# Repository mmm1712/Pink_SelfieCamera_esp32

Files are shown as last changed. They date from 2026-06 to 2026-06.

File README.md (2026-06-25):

# PocketCam: Pink ESP32S3 DIY Camera

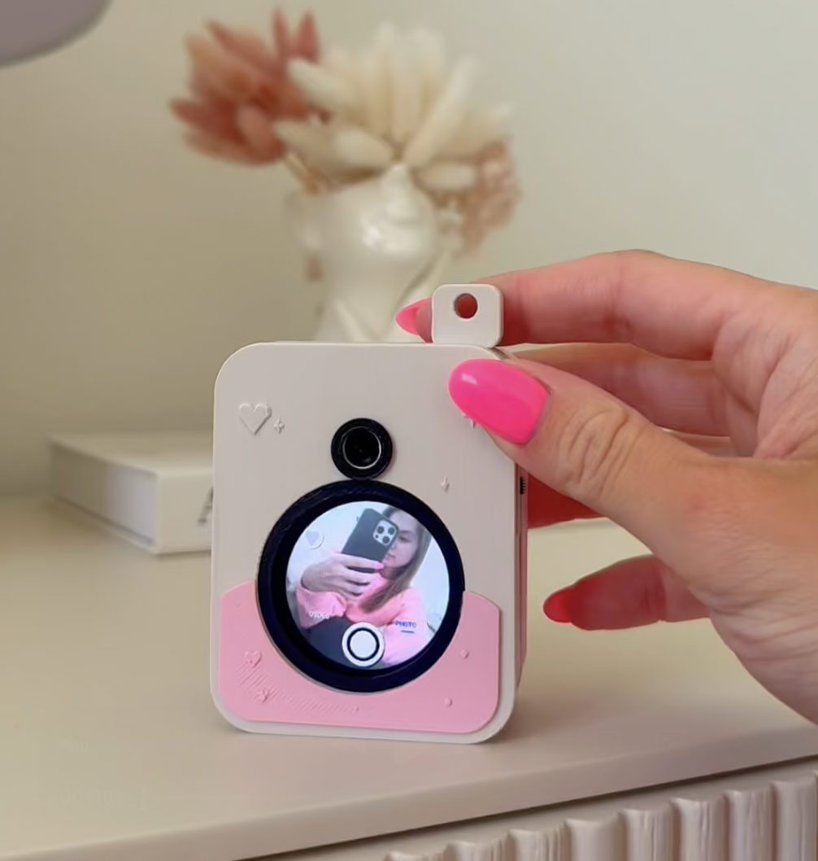
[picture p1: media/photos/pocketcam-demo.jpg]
PocketCam demo


## Demo Video

PocketCam demo video (https://youtu.be/CbtFV22GO2s)

Watch the full build/demo video on YouTube: https://youtu.be/CbtFV22GO2s

A tiny pink DIY camera built with a Seeed XIAO ESP32S3 Sense, an OV3660 camera module, a round display, microSD storage, a LiPo battery, and a custom 3D printed enclosure.

The goal of this project was to make a small camera that feels more like a real mini product than a loose electronics prototype. PocketCam shows a live preview on the round screen, captures photos and videos, saves them to microSD, creates its own local Wi-Fi network, and lets an iPhone connect directly to sync photos into a custom SwiftUI app.

This repository includes the ESP32 firmware, iPhone app, 3D printed enclosure files, hardware notes, and documentation for the project.

## What Makes It Interesting

* The ESP32S3 acts as a standalone camera and local Wi-Fi access point.
* The camera exposes a small HTTP API for syncing photos and videos.
* The iPhone app talks directly to the camera without internet or cloud.
* Photos and videos are saved locally to the microSD card.
* The iPhone app adds a gallery, filters, and on-device Core ML enhancement.
* The enclosure was designed from scratch to make the project feel like a real small device.

## Features

* Live camera preview on a round display
* Photo and video capture
* microSD card saving
* Local Wi-Fi access point mode
* Local web server for syncing
* iPhone SwiftUI app for gallery and photo sync
* Photo filters
* On-device Enhance feature using a compact Real-ESRGAN Core ML model
* Custom OpenSCAD 3D printed enclosure
* Battery-powered design with a physical power switch
* Small product-style case instead of a breadboard prototype

## Hardware

Main parts used:

| Part | Description |
| --- | --- |
| Seeed XIAO ESP32S3 Sense | Main microcontroller board |
| OV3660 camera module | Camera sensor |
| Seeed round display for XIAO | 1.28 inch round display |
| microSD card | Local photo/video storage |
| LiPo battery | Portable power |
| Slide switch | Main power switch |
| Custom 3D printed enclosure  | Front shell, back cover, openings, and internal fit |
| Screws / brass inserts | Used for assembly |
| Small wires / heat tape | Internal wiring and insulation |

## Software / Firmware

The ESP32 firmware handles the main camera behavior:

* Camera initialization
* Round display live preview
* Photo and video capture
* Saving files to microSD
* Creating a local Wi-Fi access point
* Running a small local web server
* Sending saved files to the iPhone app

The camera creates its own Wi-Fi network, so it does not need internet or a router. The iPhone connects directly to the camera and downloads files over the local network.

## Camera API

The ESP32 hosts a small local HTTP server used by the iPhone app.

Example endpoints:

```txt
GET /status.json
GET /photos.json?since=0&limit=12
GET /photo?id=123
GET /latest
GET /videos.json?since=0&limit=1
GET /video?id=5
GET /capture
```

These endpoints are used to check the camera status, list saved media, download photos/videos, and trigger capture from the app.

## iPhone App

The iPhone app was built with SwiftUI.

It can:

* Connect to the PocketCam Wi-Fi network
* Check for saved photos
* Sync photos from the camera
* Show photos in a gallery
* Apply additional filters
* Run an on-device Enhance feature using a compact Real-ESRGAN Core ML model

The app is not meant to be a full production camera app. It is a companion app for the hardware prototype and helps make the project feel more complete.

## 3D Printed Enclosure

The enclosure was designed in OpenSCAD and 3D printed.

The case includes:

* Round display opening
* Camera/lens opening
* Back cover
* Screw bosses
* Battery space
* Power switch opening
* Internal space for the XIAO ESP32S3 Sense and wiring

A big part of this project was making the camera look and feel like a real small device, not just a working prototype. I spent a lot of time adjusting the case design, screw bosses, display opening, lens opening, back cover, and internal fit so the electronics could fit inside a small enclosure.

## Folder Structure

```txt
Pink_SelfieCamera_esp32/
├── README.md
├── firmware/
│   └── README.md
├── ios-app/
│   └── README.md
├── enclosure/
│   ├── README.md
│   ├── openscad/
│   └── stl/
├── hardware/
│   └── BOM.md
├── docs/
│   ├── images/
│   ├── wiring.md
│   ├── assembly.md
│   └── sync-flow.md
└── media/
    ├── photos/
    └── videos/
```

## How It Works

PocketCam has three main parts:

1. **ESP32S3 camera firmware**
   The ESP32S3 reads from the camera module, shows a live preview on the round display, and saves captured photos/videos to the microSD card.

2. **Local Wi-Fi sync**
   The camera creates its own Wi-Fi access point. The iPhone connects directly to that network and communicates with the ESP32 through local HTTP endpoints.

3. **iPhone gallery app**
   The SwiftUI app checks the camera for saved files, downloads them, and shows them in a simple gallery. The app also includes filters and on-device photo enhancement.

Basic flow:

```txt
Camera module
   ↓
ESP32S3 firmware
   ↓
Round display live preview
   ↓
Save photo/video to microSD
   ↓
Create local Wi-Fi network
   ↓
iPhone connects directly
   ↓
SwiftUI app syncs photos into gallery
   ↓
Filters + on-device Enhance
```

## Limitations

This is still a DIY prototype, so there are some limitations:

* Image quality is limited by the small camera module.
* Preview frame rate is not as smooth as a phone camera.
* Wi-Fi sync is local only.
* Battery life depends on battery size, display usage, and Wi-Fi activity.
* The enclosure may need small tolerance adjustments depending on the 3D printer.
* Internal wiring is compact and needs careful assembly.
* The iPhone app is currently a companion app, not a full App Store-ready product.

## Future Improvements

Possible next steps:

* Design a custom PCB to reduce wiring
* Improve battery charging and power management
* Make the enclosure easier to assemble
* Improve video recording stability
* Add more camera modes
* Improve sync speed
* Polish the iPhone app UI
* Add a full beginner-friendly assembly guide
* Add better face-centered crop or portrait-style effects
* Improve internal mounting for the display, battery, and switch

## Credits

AI photo enhancement is based on [Real-ESRGAN](https://github.com/xinntao/Real-ESRGAN).

The model is used as a compact Core ML model for on-device inference inside the iPhone app. I integrated it into the app; I did not train Real-ESRGAN from scratch.

Hardware is based around the Seeed XIAO ESP32S3 Sense and the Seeed round display for XIAO.

## Project Status

Working prototype. Still improving the enclosure, wiring, app UI, and overall polish.

## License

Code is licensed under the MIT License. See [LICENSE](LICENSE).

OpenSCAD and STL enclosure files are licensed under Creative Commons Attribution 4.0 International — CC BY 4.0. See [LICENSE-CAD.md](LICENSE-CAD.md).

Real-ESRGAN and any related model files follow their own upstream license and credits.

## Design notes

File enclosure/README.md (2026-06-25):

# 3D Printed Enclosure

This folder contains the 3D printed enclosure files for the Pink Selfie Camera ESP32 project.

The enclosure was designed to make the camera feel more like a real small product instead of a loose electronics prototype.

## Design Goals

The case was designed around:

* Seeed XIAO ESP32S3 Sense
* OV3660 camera module
* Seeed round display for XIAO
* LiPo battery
* Slide power switch
* Internal wiring
* Screw bosses and back cover

The main goal was to fit all electronics inside a small pink camera-style enclosure while keeping the round display and camera opening visible from the front.

## Folder Structure

```txt
enclosure/
├── README.md
├── openscad/
│   └── .scad files
└── stl/
    └── .stl files
```

## OpenSCAD Files

The `openscad/` folder contains the editable CAD source files.

Use these files if you want to modify the case design, adjust tolerances, change screw boss length, or update the internal layout.

## STL Files

The `stl/` folder contains exported 3D printable files.

Use these files if you just want to print the enclosure without editing the OpenSCAD design.

## Enclosure Features

* Round display opening
* Camera/lens opening
* Back cover
* Screw bosses
* Battery space
* Power switch opening
* Internal room for the XIAO ESP32S3 Sense
* Space for wires and insulation
* Small product-style shape

## Print Notes

This is a compact enclosure, so small tolerance differences can matter.

Recommended checks after printing:

* Make sure the round display fits
* Make sure the camera opening is clear
* Check that the back cover closes
* Check that screw bosses are not too tight
* Make sure the switch opening is usable
* Confirm the battery is not squeezed

## Prototype Notes

The enclosure went through multiple design changes to improve fit, back cover alignment, screw bosses, display opening, lens opening, and internal hardware placement.

This version is still a prototype, so small adjustments may be needed depending on printer calibration, filament, screws, and final hardware placement.

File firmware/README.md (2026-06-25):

# ESP32 Firmware

This folder contains the firmware for the Pink Selfie Camera ESP32 project.

The firmware runs on the Seeed XIAO ESP32S3 Sense and controls the camera, round display, microSD storage, local Wi-Fi access point, and sync endpoints.

## Main Responsibilities

The firmware handles:

* Initializing the OV3660 camera module
* Showing a live preview on the round display
* Capturing photos and videos
* Saving media files to the microSD card
* Creating a local Wi-Fi access point
* Running a small local web server
* Providing endpoints for the iPhone app to sync media

## Hardware Target

Main board:

```txt
Seeed XIAO ESP32S3 Sense
```

Main connected parts:

```txt
OV3660 camera module
Seeed round display for XIAO
microSD card
LiPo battery
Power switch
```

## Local Wi-Fi Mode

The camera runs in access point mode.

This means the ESP32 creates its own Wi-Fi network, and the iPhone connects directly to it.

Example public/demo settings:

```cpp
const char* ssid = "PocketCam-0001";
const char* password = "change_this_password";
```

Do not upload private Wi-Fi passwords or personal credentials to GitHub.

## Camera API

The firmware exposes a small local HTTP API.

Example endpoints:

```txt
GET /status.json
GET /photos.json?since=0&limit=12
GET /photo?id=123
GET /latest
GET /videos.json?since=0&limit=1
GET /video?id=5
GET /capture
```

The iPhone app uses these endpoints to check status, list media, download photos/videos, and trigger capture.

## Notes

This firmware is built for a working prototype. The current focus is making the hardware, display, storage, Wi-Fi sync, and iPhone app work together in one small camera.

Future firmware improvements could include:

* Cleaner state machine
* Better video recording stability
* Faster sync
* More reliable reconnect behavior
* Better battery/power handling
* More camera settings
* Improved UI feedback on the round display

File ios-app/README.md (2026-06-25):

# iPhone App

This folder contains the iPhone companion app for the Pink Selfie Camera ESP32 project.

The app was built with SwiftUI and is used to connect to the camera, sync photos, show them in a gallery, apply filters, and run an on-device Enhance feature.

## What the App Does

The app can:

* Connect to the PocketCam Wi-Fi network
* Check the ESP32 camera status
* List saved photos and videos
* Sync new photos from the camera
* Display synced photos in a gallery
* Apply photo filters
* Run an on-device Enhance feature using a compact Real-ESRGAN Core ML model

## How It Connects

The camera creates its own local Wi-Fi network.

The iPhone connects directly to that network, then the app communicates with the ESP32 through local HTTP endpoints.

Example camera address:

```txt
http://192.168.10.1
```

Example endpoints used by the app:

```txt
/status.json
/photos.json
/photo?id=123
/latest
/videos.json
/video?id=5
/capture
```

## On-Device Enhance

The app includes an Enhance feature using a compact Real-ESRGAN Core ML model.

This runs locally on the iPhone. It does not require internet or cloud processing.

I integrated the Core ML model into the app, but I did not train Real-ESRGAN from scratch.

## Current Prototype Notes

This app is a companion app for the hardware prototype, not a full production App Store camera app.

Future app improvements could include:

* More polished UI
* Better sync progress indicators
* Faster thumbnail loading
* More reliable reconnect behavior
* Better photo/video organization
* Settings screen for camera options
* Cleaner delete/select flow

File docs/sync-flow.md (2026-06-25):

# Sync Flow

PocketCam syncs photos from the ESP32 camera to the iPhone app over a local Wi-Fi connection.

The camera does not need internet, a router, or cloud storage. The ESP32 creates its own Wi-Fi network, and the iPhone connects directly to it.

## Basic Flow

```txt
PocketCam powers on
      ↓
ESP32S3 starts camera + round display
      ↓
Photos/videos are saved to microSD
      ↓
ESP32S3 creates a local Wi-Fi access point
      ↓
iPhone connects to the PocketCam Wi-Fi network
      ↓
SwiftUI app talks to the ESP32 local web server
      ↓
App downloads photos/videos into the phone gallery
```

## Local Wi-Fi

The ESP32S3 runs in access point mode.

That means the camera creates its own Wi-Fi network instead of connecting to a home router.

Example:

```txt
Wi-Fi name: PocketCam-0001
Password: change_this_password
IP address: 192.168.10.1
```

## Local Web Server

The ESP32 hosts a small local HTTP server.

The iPhone app uses simple endpoints to check camera status, list saved files, and download media.

Example endpoints:

```txt
GET /status.json
GET /photos.json?since=0&limit=12
GET /photo?id=123
GET /latest
GET /videos.json?since=0&limit=1
GET /video?id=5
GET /capture
```

## Photo Sync

Photos are saved to the microSD card first.

Then the iPhone app asks the camera which files are available, downloads the new ones, and shows them in a gallery.

```txt
Photo captured
      ↓
Saved to microSD
      ↓
Listed by ESP32 web server
      ↓
Downloaded by iPhone app
      ↓
Displayed in SwiftUI gallery
```

## Why This Design

I chose local Wi-Fi sync because it keeps the project simple and portable.

Benefits:

* No internet required
* No cloud account required
* Photos stay local unless synced
* The camera can work anywhere
* The iPhone app can communicate directly with the hardware

## Current Prototype Notes

This sync system is designed for a small DIY prototype. It works well for local photo transfer, but it is not meant to be a high-speed production camera system.

Future improvements could include faster sync, better file indexing, progress indicators, and more reliable reconnect behavior.

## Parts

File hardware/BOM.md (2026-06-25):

# Bill of Materials

Main hardware used for the Pink Selfie Camera ESP32 project.

| Part | Purpose | Notes |
| --- | --- | --- |
| Seeed XIAO ESP32S3 Sense | Main microcontroller | Runs the camera firmware, Wi-Fi server, and microSD logic |
| OV3660 camera module | Camera sensor | Used for live preview and photo/video capture |
| Seeed Round Display for XIAO | Camera screen | Shows the live round preview |
| microSD card | Local storage | Stores captured photos and videos |
| LiPo battery | Portable power | Powers the camera without USB |
| Slide power switch | Power control | Used to turn the camera on/off |
| 3D printed front shell | Enclosure | Custom designed in OpenSCAD |
| 3D printed back cover | Enclosure | Covers electronics and battery |
| Screws / brass inserts | Assembly | Used to close the enclosure |
| Small wires | Internal wiring | Used for battery and switch connections |
| Heat tape / insulation tape  | Safety | Covers solder joints and prevents shorts |

## Notes

This project is built as a compact prototype, so the internal space is limited. The battery, switch, display, camera module, and wiring all need to fit inside the 3D printed enclosure.

The exact battery size and screw lengths may need small adjustments depending on the final case version and 3D print tolerances.

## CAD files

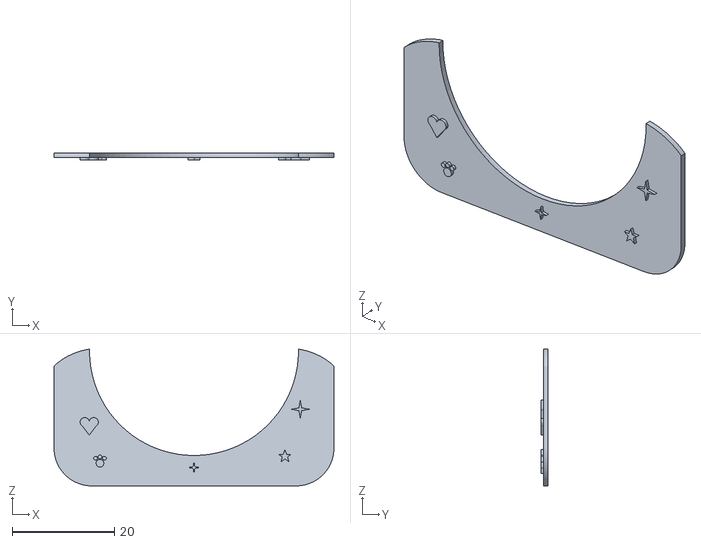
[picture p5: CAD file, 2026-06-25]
enclosure/stl/accent_panel.stl
54.8 x 1.46 x 26.8

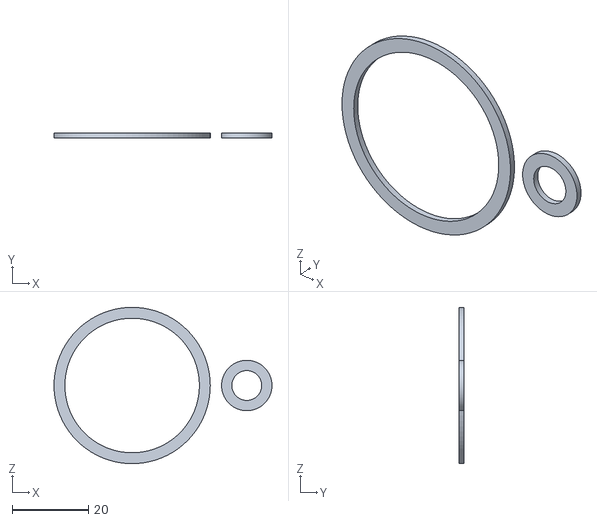
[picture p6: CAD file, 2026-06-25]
enclosure/stl/bezel_rings.stl
57.0 x 1.25 x 40.9

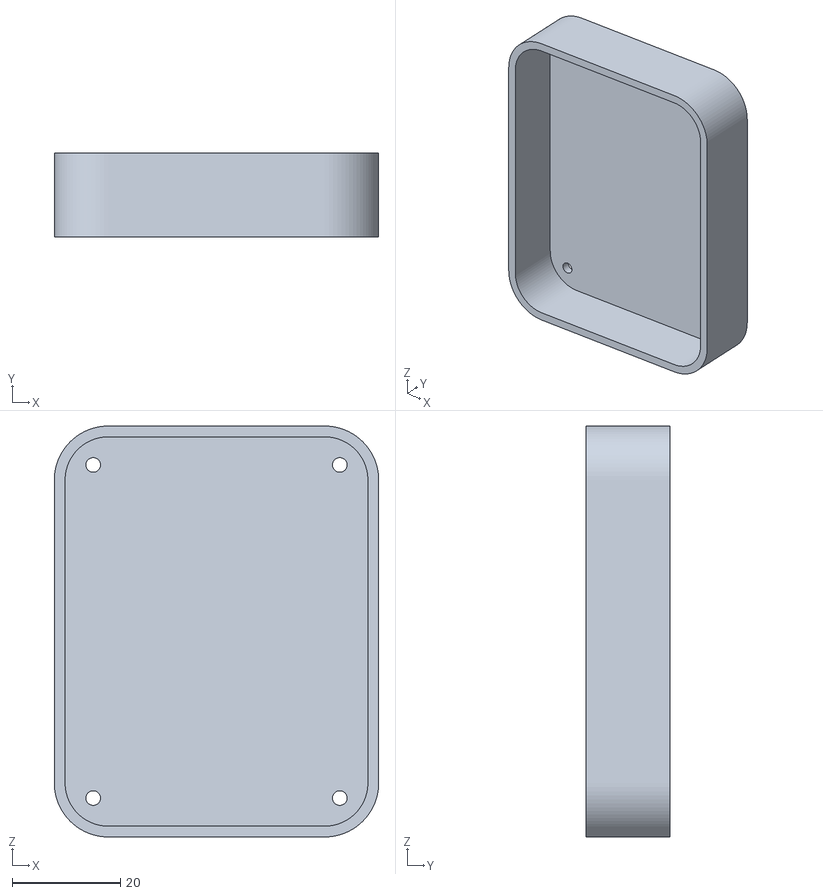
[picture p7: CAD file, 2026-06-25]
enclosure/stl/back_cover.stl
60.0 x 15.5 x 76.0

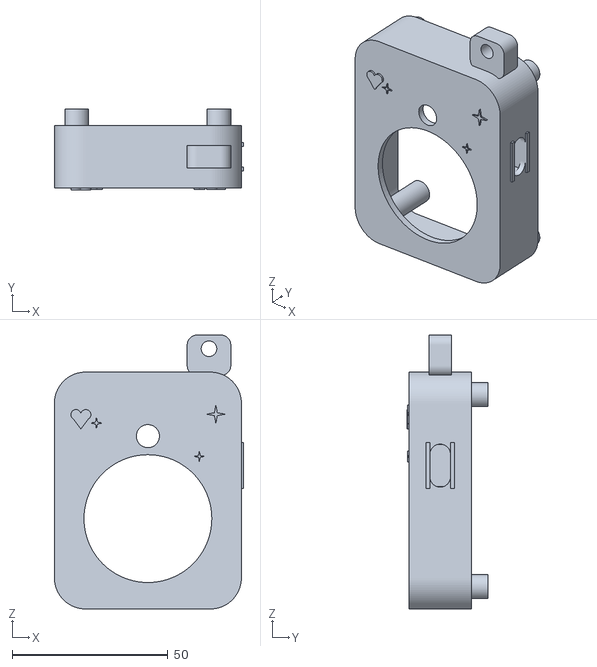
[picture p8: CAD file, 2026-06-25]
enclosure/stl/front_shell.stl
60.7 x 26.0 x 87.9

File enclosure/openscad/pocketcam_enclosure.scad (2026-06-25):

$fn = 80;


// part = "assembly";
// part = "back_cover";
// part = "accent_panel";
// part = "bezel_rings";
// part = "front_fit_test";
// part = "battery_fit_test";
// part = "display_screw_template";
// part = "front_shell";

part = "front_shell";


body_w = 60;

body_h_base = 66;
top_extra = 10;
body_h = body_h_base + top_extra;

body_z_shift = top_extra / 2;
body_bottom_z = -body_h_base / 2;
body_top_z = body_bottom_z + body_h;

front_depth = 20.0;


back_depth = 20.5;


lid_lip_depth = 5.0;
lid_lip_wall = 1.2;
lid_lip_clearance = 0.65;
lip_overlap = 2.0;   


back_outer_depth = back_depth - lid_lip_depth;

body_depth = front_depth + back_outer_depth;

corner_r = 10.0;
wall = 2.0;
front_face_t = 2.3;
clearance = 0.45;

xiao_w = 21.0;
xiao_h = 17.8;
xiao_t = 3.2;
xiao_sense_stack_t = 15.0;

round_display_pcb_d = 39.0;
round_display_visible_d = 34.5;
round_display_recess_d = 41.0;

battery_w = 33.0;
battery_h = 43.0;
battery_t = 10.5;

lens_hole_d = 7.4;
lens_bezel_outer_d = 12.2;
lens_bezel_inner_d = 7.8;

screen_z = -4.0;
lens_z = screen_z + round_display_visible_d/2 + 9.2;

display_screw_clearance_r = 1.18;  
display_screw_head_r = 2.55;       
display_screw_head_depth = 1.35;
display_screw_boss_r = 3.35;      
display_screw_boss_depth = 3.0;


corner_extension_receiver_r = 4.65;  
corner_extension_receiver_depth = 6.0;
corner_extension_receiver_y = -back_depth/2 + corner_extension_receiver_depth/2 - 0.05;


display_hug_outer_r = display_screw_boss_r;       
display_hug_inner_r = display_screw_clearance_r;  
display_hug_depth = 5.0;
display_hug_y = back_depth/2 - wall - display_hug_depth/2 + 0.10;


xiao_back_side_hugs_enabled = true;
xiao_back_hug_depth = 5.0;
xiao_back_hug_t = 1.25;
xiao_back_hug_h = 18.0;
xiao_back_hug_extra_gap = 1.1;
xiao_back_hug_y = back_depth/2 - wall - xiao_back_hug_depth/2 + 0.10;
xiao_back_hug_z = xiao_mount_z;



display_screw_positions = [
    [  0.000, screen_z + 19.431],
    [-11.811, screen_z - 15.621],
    [ 11.811, screen_z - 15.621]
];


round_display_locator_clearance = 0.55;
round_display_locator_inner_r = round_display_pcb_d/2 + round_display_locator_clearance;
round_display_locator_wall = 1.45;
round_display_locator_outer_r = round_display_locator_inner_r + round_display_locator_wall;
round_display_locator_depth = 3.2;
round_display_locator_y = -front_depth/2 + front_face_t + round_display_locator_depth/2 - 0.05;


xiao_mount_clearance = 0.85;
xiao_mount_w = xiao_h + 2*xiao_mount_clearance;
xiao_mount_h = xiao_w + 2*xiao_mount_clearance;


xiao_display_gap = 1.35;
xiao_mount_bottom_z = screen_z + round_display_locator_outer_r + xiao_display_gap;
xiao_mount_z = xiao_mount_bottom_z + xiao_mount_h/2;


xiao_rail_t = 1.20;
xiao_rail_depth = 7.2;
xiao_rail_y = -front_depth/2 + front_face_t + xiao_rail_depth/2 + 0.25;


xiao_bottom_stop_t = 1.25;
xiao_support_h = 10.5;
xiao_support_center_z = xiao_mount_bottom_z + xiao_support_h/2;


screw_margin = 7.2;
screw_x = body_w/2 - screw_margin;

screw_positions = [
    [-screw_x, body_bottom_z + screw_margin],
    [ screw_x, body_bottom_z + screw_margin],
    [-screw_x, body_top_z    - screw_margin],
    [ screw_x, body_top_z    - screw_margin]
];


key_tab_w = 14.0;
key_tab_h = 13.0;
key_tab_d = 7.2;
key_hole_d = 5.0;
key_tab_x = body_w/2 - key_tab_w/2 - 3.4;


switch_slot_z = 13;

switch_slot_h = 13.8;
switch_slot_w = 6.6;


accent_panel_inset = 2.6;
accent_panel_w = body_w - 2*accent_panel_inset;
accent_panel_bottom_z = body_bottom_z + accent_panel_inset;
accent_panel_base_h = 23.0;
accent_panel_cheek_r = 13.4;
accent_panel_cheek_x = accent_panel_w/2 - 9.2;
accent_panel_cheek_z = accent_panel_bottom_z + 18.0;
accent_panel_top_z = accent_panel_cheek_z + accent_panel_cheek_r;
accent_panel_h = accent_panel_top_z - accent_panel_bottom_z;
accent_panel_z = (accent_panel_top_z + accent_panel_bottom_z)/2;
accent_panel_corner_r = max(corner_r - accent_panel_inset, 1);
accent_panel_screen_cutout_r = round_display_visible_d/2 + 3.2;
accent_panel_t = 0.95;


relief_t = 0.75;
tiny_relief_t = 0.55;

front_decor_y = -front_depth/2 - relief_t/2 + 0.10;
accent_decor_y = -accent_panel_t/2 - tiny_relief_t/2 + 0.04;

cute_label_text = "PocketCam";
cute_sub_text = "selfie cam";


module rounded_rect_2d(w, h, r) {
    hull() {
        translate([ w/2-r,  h/2-r]) circle(r=r);
        translate([-w/2+r,  h/2-r]) circle(r=r);
        translate([ w/2-r, -h/2+r]) circle(r=r);
        translate([-w/2+r, -h/2+r]) circle(r=r);
    }
}


module rounded_prism(w, h, d, r) {
    rotate([90,0,0])
        linear_extrude(height=d, center=true, convexity=10)
            rounded_rect_2d(w, h, r);
}

module cyl_y(h, r) {
    rotate([90,0,0]) cylinder(h=h, r=r, center=true);
}

module cyl_x(h, r) {
    rotate([0,90,0]) cylinder(h=h, r=r, center=true);
}

module accent_panel_body_clip_2d() {
    translate([0, body_z_shift])
        rounded_rect_2d(
            accent_panel_w,
            body_h - 2*accent_panel_inset,
            accent_panel_corner_r
        );
}

module accent_panel_soft_blob_2d() {
    union() {

        translate([0, accent_panel_bottom_z + accent_panel_base_h/2])
            rounded_rect_2d(
                accent_panel_w,
                accent_panel_base_h,
                accent_panel_corner_r
            );


        translate([-accent_panel_cheek_x, accent_panel_cheek_z - 1.5])
            scale([0.92, 0.78])
                circle(r=accent_panel_cheek_r);


        translate([ accent_panel_cheek_x, accent_panel_cheek_z - 1.5])
            scale([0.92, 0.78])
                circle(r=accent_panel_cheek_r);


        translate([0, accent_panel_bottom_z + 9.0])
            rounded_rect_2d(accent_panel_w - 13.0, 16.0, 6.0);
    }
}


accent_tip_trim_r = 1.35;
accent_tip_trim_x = 16.9;
accent_tip_trim_z = screen_z + 6.8;

accent_end_soft_cut_r = 2;
accent_end_soft_cut_x = 16.7;
accent_end_soft_cut_z = screen_z + 6.5;

module accent_panel_outline_2d() {
    difference() {
        intersection() {
            accent_panel_body_clip_2d();
            accent_panel_soft_blob_2d();
        }


        translate([0, screen_z])
            circle(r=accent_panel_screen_cutout_r);
    }
}

module accent_panel_prism(t) {
    rotate([90,0,0])
        linear_extrude(height=t, center=true, convexity=10)
            accent_panel_outline_2d();
}


module front_extrude(t) {
    rotate([90,0,0])
        linear_extrude(height=t, center=true, convexity=10)
            children();
}

module heart_2d(s=1) {
    scale([s,s])
        union() {
            translate([-2.2, 1.2]) circle(r=2.25);
            translate([ 2.2, 1.2]) circle(r=2.25);
            polygon(points=[
                [-4.5, 0.8],
                [ 4.5, 0.8],
                [ 0.0,-5.2]
            ]);
        }
}

module sparkle_2d(s=1) {
    scale([s,s])
        union() {
            polygon(points=[
                [0, 5.2],
                [0.8, 0.8],
                [5.2, 0],
                [0.8,-0.8],
                [0,-5.2],
                [-0.8,-0.8],
                [-5.2,0],
                [-0.8,0.8]
            ]);
        }
}

module tiny_star_2d(s=1) {
    scale([s,s])
        polygon(points=[
            [0,5.0], [1.3,1.5], [4.8,1.5], [2.0,-0.5],
            [3.0,-4.2], [0,-2.0], [-3.0,-4.2], [-2.0,-0.5],
            [-4.8,1.5], [-1.3,1.5]
        ]);
}

module paw_2d(s=1) {
    scale([s,s])
        union() {
            translate([0,-1.0]) circle(r=2.1);
            translate([-2.4,1.7]) circle(r=1.05);
            translate([0,2.4]) circle(r=1.05);
            translate([2.4,1.7]) circle(r=1.05);
        }
}

module raised_heart(x, z, s=1.0, t=relief_t) {
    translate([x, front_decor_y, z])
        front_extrude(t)
            heart_2d(s);
}

module raised_sparkle(x, z, s=1.0, t=tiny_relief_t) {
    translate([x, front_decor_y, z])
        front_extrude(t)
            sparkle_2d(s);
}

module raised_star(x, z, s=1.0, t=tiny_relief_t) {
    translate([x, front_decor_y, z])
        front_extrude(t)
            tiny_star_2d(s);
}

module raised_paw(x, z, s=1.0, t=tiny_relief_t) {
    translate([x, front_decor_y, z])
        front_extrude(t)
            paw_2d(s);
}


module front_toy_camera_relief() {

    raised_heart(-21.5, body_top_z - 14.5, 0.72);
    raised_sparkle( 21.8, body_top_z - 13.5, 0.58);



    raised_sparkle(-16.5, lens_z + 4.2, 0.38, 0.45);
    raised_sparkle( 16.5, lens_z - 6.5, 0.34, 0.45);

}

module accent_panel_relief() {
    translate([-20.5, accent_decor_y, accent_panel_bottom_z + 12.0])
        front_extrude(tiny_relief_t)
            heart_2d(0.40);

    translate([20.8, accent_decor_y, accent_panel_bottom_z + 15.0])
        front_extrude(tiny_relief_t)
            sparkle_2d(0.34);

    translate([-18.4, accent_decor_y, accent_panel_bottom_z + 4.8])
        front_extrude(tiny_relief_t)
            paw_2d(0.36);

    translate([17.8, accent_decor_y, accent_panel_bottom_z + 5.8])
        front_extrude(tiny_relief_t)
            tiny_star_2d(0.26);
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

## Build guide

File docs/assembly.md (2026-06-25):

# Assembly Guide

This is a simple assembly guide for the Pink Selfie Camera ESP32 prototype.

The exact fit may change depending on the 3D print version, but this shows the general order of assembly.

## 1. Prepare the 3D Printed Parts

Print the main enclosure parts:

* Front shell
* Back cover
* Any separate decorative or support parts

Before adding electronics, check that:

* The round display fits into the front opening
* The camera/lens opening is clear
* The back cover can close
* Screw bosses are clean
* The power switch opening is not blocked

## 2. Install the Round Display

Place the Seeed round display into the front opening of the enclosure.

Make sure:

* The display is centered
* The screen is visible through the round opening
* The display is not pressed too tightly
* The wiring has space behind it

The round display is one of the main visual parts of the camera, so this fit is important.

## 3. Place the Camera Module

Position the OV3660 camera module behind the lens opening.

Check that:

* The camera is aligned with the front opening
* The lens is not blocked by the case
* The camera cable is not bent too sharply
* The preview is not rotated or angled incorrectly

## 4. Place the XIAO ESP32S3 Sense

Place the XIAO ESP32S3 Sense inside the enclosure.

Make sure there is enough space for:

* Camera connection
* Round display connection
* microSD card access
* Battery wiring
* Power switch wiring

## 5. Add the Battery

Place the LiPo battery inside the battery area.

Make sure:

* The battery is not squeezed too tightly
* Wires are not pulled
* Nothing sharp is pressing into the battery
* The back cover can still close

## 6. Wire the Power Switch

Connect the slide switch to the battery positive wire.

Basic wiring:

```txt
Battery red wire   → switch pin 1
Switch pin 2       → board power input
Battery black wire → board ground
```

Only the positive wire is switched. The ground wire stays connected.

After soldering, cover the exposed joints with heat tape or insulation tape.

## 7. Check Internal Fit

Before closing the case, check that:

* The display is still centered
* The camera module is aligned
* Wires are not blocking the display or lens
* The battery is not being crushed
* The power switch moves freely
* The back cover can close without force

## 8. Close the Back Cover

Carefully close the back cover and secure it with screws.

Do not overtighten the screws, especially if the screw bosses are 3D printed.

## 9. Power On Test

Turn on the camera and check:

* The round display turns on
* Live preview appears
* The camera can capture a photo
* Files are saved to microSD
* The Wi-Fi network appears
* The iPhone app can connect and sync photos

## Notes

This is still a prototype assembly. Some parts may need small tolerance adjustments depending on the printer, filament, screw size, and final enclosure version.

A future version could use a custom PCB to make the inside cleaner and easier to assemble.

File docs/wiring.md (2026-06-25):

# Wiring Notes

This project is built as a compact battery-powered prototype, so the wiring is intentionally simple.

The main wired parts are the LiPo battery, slide power switch, Seeed XIAO ESP32S3 Sense, round display, camera module, and microSD storage.

## Round Display

The camera uses a Seeed round display for XIAO as the main screen.

The round display shows the live camera preview, so the camera feels like a real small device instead of just an ESP32 saving photos in the background.

Because the display sits in the front opening of the enclosure, the internal wiring needs to stay clear of the display area. The wires should be routed so they do not press against the display, block the camera opening, or stop the back cover from closing.

## Power Switch

The camera is powered by a LiPo battery. I added a small slide switch so the camera can be turned on and off without unplugging the battery.

The basic idea:

```txt
LiPo Battery +
      ↓
Slide Switch
      ↓
XIAO ESP32S3 battery/power input
```

Only the positive power wire is switched. The ground wire stays connected.

## Simple Switch Wiring

```txt
Battery red wire   → switch pin 1
Switch pin 2       → board power input
Battery black wire → board ground
```

The switch works like a small gate:

* **ON**: power flows to the board
* **OFF**: power is disconnected

## Camera and microSD

The camera module connects to the XIAO ESP32S3 Sense and is used for live preview, photo capture, and video capture.

Photos and videos are saved to the microSD card first. The iPhone app can then connect over local Wi-Fi and sync the saved files from the camera.

## Insulation

After soldering the switch wires, I covered the exposed solder joints with heat tape / insulation tape to reduce the chance of shorts inside the case.

Because the enclosure is small, the wires can easily touch the board, battery, display module, or camera module. Covering exposed metal is important.

## Internal Wiring Notes

The final enclosure has limited space, so the wiring needs to be:

* Short enough to fit inside the case
* Flexible enough to close the back cover
* Insulated anywhere metal is exposed
* Routed away from the round display and camera opening when possible
* Placed so it does not press too hard against the battery or display

## Current Prototype Notes

This wiring is part of the prototype version. A future version could use a custom PCB to reduce loose wires and make assembly cleaner.

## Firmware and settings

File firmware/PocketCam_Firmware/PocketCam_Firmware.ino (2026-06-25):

#include <Arduino.h>
#include <Wire.h>
#include <SPI.h>
#include <SD.h>
#include "esp_camera.h"
#include "img_converters.h"
#include <WiFi.h>
#include <WebServer.h>
#include <Arduino_GFX_Library.h>

// ===============================
// Sticker Engine prototypes
// ===============================
bool isStickerModeEnabled();
bool tryHandleStickerTouch(uint8_t x, uint8_t y);
void drawStickerPreviewToCanvas();
void drawStickerIconDirect();
bool saveStickerJPG(camera_fb_t *fb, String path);
bool encodeStickerFrameJPG(camera_fb_t *fb, uint8_t **jpgBuf, size_t *jpgLen, int quality);
void pollTouchDuringDraw();

// ===============================
// Round Display pins
// ===============================
#define LCD_CS   D1
#define LCD_DC   D3
#define LCD_SCK  D8
#define LCD_MOSI D10
#define LCD_MISO D9
#define LCD_RST  GFX_NOT_DEFINED
#define LCD_BL   D6

#define ROUND_SD_CS D2

// Touch
#define TOUCH_INT D7
#define CHSC6X_I2C_ID 0x2E
#define CHSC6X_READ_POINT_LEN 5

#define SPI_SPEED 40000000
#define CAMERA_INIT_XCLK_HZ 20000000
#define CAMERA_FAST_XCLK_MHZ 24

// ===============================
// Camera pins — XIAO ESP32S3 Sense
// ===============================
#define PWDN_GPIO_NUM   -1
#define RESET_GPIO_NUM  -1
#define XCLK_GPIO_NUM   10
#define SIOD_GPIO_NUM   40
#define SIOC_GPIO_NUM   39

#define Y9_GPIO_NUM     48
#define Y8_GPIO_NUM     11
#define Y7_GPIO_NUM     12
#define Y6_GPIO_NUM     14
#define Y5_GPIO_NUM     16
#define Y4_GPIO_NUM     18
#define Y3_GPIO_NUM     17
#define Y2_GPIO_NUM     15

#define VSYNC_GPIO_NUM  38
#define HREF_GPIO_NUM   47
#define PCLK_GPIO_NUM   13

// Stable live preview.
// Keep capture in the same RGB565/QVGA mode as preview for stability.
// The XIAO ESP32S3 Sense can restart when switching to JPEG high-res at shutter time.
#define PREVIEW_FRAME_SIZE FRAMESIZE_QVGA
#define PHOTO_CAPTURE_FRAME_SIZE FRAMESIZE_QVGA
#define ENABLE_EXPERIMENTAL_HQ_PHOTO 0
#define HQ_PHOTO_FRAME_SIZE FRAMESIZE_VGA
#define HQ_PHOTO_FALLBACK_FRAME_SIZE FRAMESIZE_QVGA
#define HQ_PHOTO_JPEG_QUALITY 10

// ===============================
// Wi-Fi
// ===============================
const char* AP_SSID = "your_camera_ssid";
const char* AP_PASSWORD = "your_camera_password";

IPAddress AP_IP(192, 168, 10, 1);
IPAddress AP_GATEWAY(192, 168, 10, 1);
IPAddress AP_SUBNET(255, 255, 255, 0);

WebServer server(80);

// ===============================
// Display
// ===============================
Arduino_DataBus *bus = new Arduino_ESP32SPI(
  LCD_DC, LCD_CS, LCD_SCK, LCD_MOSI, LCD_MISO
);

Arduino_GFX *gfx = new Arduino_GC9A01(
  bus, LCD_RST, 0, true
);

Arduino_Canvas *canvas = new Arduino_Canvas(240, 240, gfx);

// ===============================
// Colors
// ===============================
#define C_BLACK      BLACK
#define C_WHITE      WHITE
#define C_GRAY       0x8410
#define C_SOFT_GRAY  0xBDF7
#define C_IOS_BLUE   0x03DF
#define C_RED        0xF800
#define C_GREEN      0x07E0

// ===============================
// State
// ===============================
int currentMode = 1; // 0 = VIDEO, 1 = PHOTO
bool isRecording = false;
bool isCapturing = false;

bool sdOK = false;
bool cameraOK = false;

int latestPhotoId = 0;
int nextPhotoId = 1;

int latestVideoId = 0;
int nextVideoId = 1;

File videoFile;
int currentVideoId = 0;
int videoFrameCount = 0;
int videoFrameFailCount = 0;
unsigned long videoStartMs = 0;
unsigned long lastVideoFrameMs = 0;

const unsigned long VIDEO_FRAME_INTERVAL_MS = 200; // about 5 FPS
const unsigned long MAX_VIDEO_MS = 30000;

const int API_DEFAULT_LIMIT = 40;
const int API_MAX_LIMIT = 40;

bool wasTouching = false;
unsigned long lastTouchMs = 0;
unsigned long lastTouchPollMs = 0;
bool pendingTouchTap = false;
uint8_t pendingTouchX = 0;
uint8_t pendingTouchY = 0;

const unsigned long TOUCH_TAP_DEBOUNCE_MS = 70;
const unsigned long TOUCH_POLL_DURING_DRAW_MS = 12;
const unsigned long SHUTTER_ACTION_COOLDOWN_MS = 320;
const int TOUCH_READ_RETRIES = 3;
const int SHUTTER_TOUCH_RADIUS = 48;
unsigned long lastShutterActionMs = 0;

unsigned long lastPreviewMs = 0;
const unsigned long PREVIEW_INTERVAL_MS = 66; // target about 15 FPS

bool showSplash = true;
unsigned long splashStartMs = 0;
const unsigned long SPLASH_DURATION_MS = 1200;

String statusText = "Starting";

unsigned long photoFlashUntilMs = 0;
unsigned long photoSavedUntilMs = 0;
int lastSavedPhotoId = 0;

const unsigned long PHOTO_FLASH_MS = 140;
const unsigned long PHOTO_SAVED_MS = 900;

unsigned long previewStatsStartMs = 0;
unsigned long previewStatsDrawMs = 0;
unsigned long previewStatsFlushMs = 0;
unsigned int previewStatsFrames = 0;

// ===============================
// Helpers
// ===============================
void setBacklight(uint8_t brightness) {
  pinMode(LCD_BL, OUTPUT);
  digitalWrite(LCD_BL, HIGH);
}

String photoPathFromId(int id) {
  char path[48];
  sprintf(path, "/photos/IMG_%06d.jpg", id);
  return String(path);
}

String videoPathFromId(int id) {
  char path[48];
  sprintf(path, "/videos/VID_%06d.mjpg", id);
  return String(path);
}

String photoFilenameFromId(int id) {
  char name[28];
  sprintf(name, "IMG_%06d.jpg", id);
  return String(name);
}

String videoFilenameFromId(int id) {
  char name[30];
  sprintf(name, "VID_%06d.mjpg", id);
  return String(name);
}

int parseIdFromName(String name, const char *prefix, const char *ext) {
  int start = name.indexOf(prefix);
  int end = name.indexOf(ext);
  if (start < 0 || end < 0 || end <= start + 4) return -1;
  String idString = name.substring(start + 4, end);
  return idString.toInt();
}

bool isInsideCircle(int x, int y, int cx, int cy, int r) {
  int dx = x - cx;
  int dy = y - cy;
  return (dx * dx + dy * dy) <= (r * r);
}

bool isShutterTouch(int x, int y) {
  if (isInsideCircle(x, y, 120, 204, SHUTTER_TOUCH_RADIUS)) {
    return true;
  }

  return x >= 72 && x <= 168 && y >= 172 && y <= 239;
}

// ===============================
// Touch
// ===============================
bool touchIsPressed() {
  return digitalRead(TOUCH_INT) == LOW;
}

bool readTouchOnce(uint8_t *x, uint8_t *y) {
  if (!touchIsPressed()) return false;

  uint8_t data[CHSC6X_READ_POINT_LEN] = {0};

  uint8_t readLen = Wire.requestFrom(
    (uint8_t)CHSC6X_I2C_ID,
    (uint8_t)CHSC6X_READ_POINT_LEN
  );

  if (readLen == CHSC6X_READ_POINT_LEN) {
    Wire.readBytes(data, readLen);

    if (data[0] == 0x01) {
      *x = data[2];
      *y = data[4];
      return true;
    }
  }

  return false;
}

bool readTouch(uint8_t *x, uint8_t *y) {
  for (int attempt = 0; attempt < TOUCH_READ_RETRIES; attempt++) {
    if (!touchIsPressed()) return false;

    if (readTouchOnce(x, y)) {
      return true;
    }

    delay(2);
  }

  return false;
}

// ===============================
// SD
// ===============================
void scanPhotoLibrary() {
  latestPhotoId = 0;

  if (!SD.exists("/photos")) SD.mkdir("/photos");

  File root = SD.open("/photos");
  if (!root || !root.isDirectory()) {
    nextPhotoId = 1;
    return;
  }

  File file = root.openNextFile();
  while (file) {
    if (!file.isDirectory()) {
      int id = parseIdFromName(String(file.name()), "IMG_", ".jpg");
      if (id > latestPhotoId) latestPhotoId = id;
    }
    file.close();
    file = root.openNextFile();
  }

  root.close();
  nextPhotoId = latestPhotoId + 1;
}

void scanVideoLibrary() {
  latestVideoId = 0;

  if (!SD.exists("/videos")) SD.mkdir("/videos");

  File root = SD.open("/videos");
  if (!root || !root.isDirectory()) {
    nextVideoId = 1;
    return;
  }

  File file = root.openNextFile();
  while (file) {
    if (!file.isDirectory()) {
      int id = parseIdFromName(String(file.name()), "VID_", ".mjpg");
      if (id > latestVideoId) latestVideoId = id;
    }
    file.close();
    file = root.openNextFile();
  }

  root.close();
  nextVideoId = latestVideoId + 1;
}

bool setupRoundDisplaySD() {
  Serial.println("Initializing Round Display SD...");

  if (!SD.begin(ROUND_SD_CS)) {
    Serial.println("SD mount failed");
    statusText = "SD failed";
    return false;
  }

  if (SD.cardType() == CARD_NONE) {
    Serial.println("No SD card");
    statusText = "No SD";
    return false;
  }

  Serial.println("SD OK");
  Serial.printf("Card size: %llu MB\n", SD.cardSize() / (1024 * 1024));

  SD.mkdir("/photos");
  SD.mkdir("/videos");

  scanPhotoLibrary();
  scanVideoLibrary();

  statusText = "SD OK";
  return true;
}

// ===============================
// Camera
// ===============================
void flushCameraFrames(int count, int delayMs) {
  for (int i = 0; i < count; i++) {
    camera_fb_t *fb = esp_camera_fb_get();
    if (fb) {
      esp_camera_fb_return(fb);
    }
    delay(delayMs);
  }
}

void applySensorTuning() {
  sensor_t *s = esp_camera_sensor_get();
  if (!s) return;

  s->set_brightness(s, 1);
  s->set_contrast(s, 1);
  s->set_saturation(s, 1);

  s->set_whitebal(s, 1);
  s->set_awb_gain(s, 1);
  s->set_exposure_ctrl(s, 1);
  s->set_gain_ctrl(s, 1);

  s->set_hmirror(s, 0);
  s->set_vflip(s, 0);

  // These are supported in the ESP32 camera sensor API for OV2640.
  s->set_wpc(s, 1);
  s->set_lenc(s, 1);
  s->set_raw_gma(s, 1);
}

void tryFastPreviewClock() {
  sensor_t *s = esp_camera_sensor_get();
  if (!s) return;

  if (s->set_xclk && s->set_xclk(s, LEDC_TIMER_0, CAMERA_FAST_XCLK_MHZ) == 0) {
    Serial.printf("Camera XCLK set to %d MHz\n", CAMERA_FAST_XCLK_MHZ);
  } else {
    Serial.println("Camera fast XCLK not accepted; staying at default clock");
  }
}

bool setupCamera() {
  camera_config_t config;
  config.ledc_channel = LEDC_CHANNEL_0;
  config.ledc_timer   = LEDC_TIMER_0;

  config.pin_d0 = Y2_GPIO_NUM;
  config.pin_d1 = Y3_GPIO_NUM;
  config.pin_d2 = Y4_GPIO_NUM;
  config.pin_d3 = Y5_GPIO_NUM;
  config.pin_d4 = Y6_GPIO_NUM;
  config.pin_d5 = Y7_GPIO_NUM;
  config.pin_d6 = Y8_GPIO_NUM;
  config.pin_d7 = Y9_GPIO_NUM;

  config.pin_xclk  = XCLK_GPIO_NUM;
  config.pin_pclk  = PCLK_GPIO_NUM;
  config.pin_vsync = VSYNC_GPIO_NUM;
  config.pin_href  = HREF_GPIO_NUM;

  config.pin_sccb_sda = SIOD_GPIO_NUM;
  config.pin_sccb_scl = SIOC_GPIO_NUM;

  config.pin_pwdn  = PWDN_GPIO_NUM;
  config.pin_reset = RESET_GPIO_NUM;

  config.xclk_freq_hz = CAMERA_INIT_XCLK_HZ;
  config.pixel_format = PIXFORMAT_RGB565;
  config.frame_size   = PREVIEW_FRAME_SIZE;
  config.jpeg_quality = 12;
  config.fb_count     = 2;
  config.fb_location  = CAMERA_FB_IN_PSRAM;
  config.grab_mode    = CAMERA_GRAB_LATEST;

  Serial.println("Initializing camera RGB565 QVGA preview...");
  esp_err_t err = esp_camera_init(&config);

  if (err != ESP_OK) {
    Serial.printf("Camera init failed: 0x%x\n", err);
    statusText = "Camera fail";
    return false;
  }

  applySensorTuning();
  tryFastPreviewClock();
  flushCameraFrames(2, 50);

  Serial.println("Camera OK");
  statusText = "Camera OK";
  return true;
}

void recordPreviewStats(unsigned long frameStartMs, unsigned long flushStartMs, unsigned long frameEndMs) {
  if (previewStatsStartMs == 0) {
    previewStatsStartMs = frameStartMs;
  }

  previewStatsFrames++;
  previewStatsDrawMs += flushStartMs - frameStartMs;
  previewStatsFlushMs += frameEndMs - flushStartMs;

  unsigned long elapsed = frameEndMs - previewStatsStartMs;
  if (elapsed >= 1000 && previewStatsFrames > 0) {
    float fps = (previewStatsFrames * 1000.0f) / elapsed;
    Serial.printf(
      "Preview FPS: %.1f draw=%lums flush=%lums\n",
      fps,
      previewStatsDrawMs / previewStatsFrames,
      previewStatsFlushMs / previewStatsFrames
    );

    previewStatsStartMs = frameEndMs;
    previewStatsDrawMs = 0;
    previewStatsFlushMs = 0;
    previewStatsFrames = 0;
  }
}

void resetPreviewStats() {
  previewStatsStartMs = 0;
  previewStatsDrawMs = 0;
  previewStatsFlushMs = 0;
  previewStatsFrames = 0;
}

// Draw live preview from camera
void drawLivePreviewToCanvas() {
  if (!cameraOK || isCapturing) return;

  camera_fb_t *fb = esp_camera_fb_get();
  if (!fb) {
    Serial.println("Preview frame failed");
    return;
  }

  if (fb->format == PIXFORMAT_RGB565 && fb->width >= 240 && fb->height >= 240) {
    uint16_t *pixels = (uint16_t *)fb->buf;
    uint16_t *dst = canvas->getFramebuffer();
    int cropX = (fb->width - 240) / 2;

    if (!dst) {
      Serial.println("Preview framebuffer missing");
      esp_camera_fb_return(fb);
      return;
    }

    for (int y = 0; y < 240; y++) {
      uint16_t *srcLine = pixels + (y * fb->width) + cropX;
      uint16_t *dstLine = dst + (y * 240);

      for (int x = 0; x < 240; x++) {
        uint16_t p = srcLine[x];
        dstLine[x] = (p >> 8) | (p << 8);
      }

      if ((y & 0x0F) == 0) {
        pollTouchDuringDraw();
        yield();
      }
    }
  } else {
    Serial.printf(
      "Bad preview frame: %dx%d format=%d len=%u\n",
      fb->width,
      fb->height,
      fb->format,
      (unsigned)fb->len
    );
  }

  esp_camera_fb_return(fb);
}

// ===============================
// Overlay UI
// ===============================
void drawTextWithShadowDirect(const char *text, int x, int y, uint16_t color) {
  canvas->setTextSize(1);
  canvas->setTextColor(C_BLACK);
  canvas->setCursor(x + 1, y + 1);
  canvas->print(text);

  canvas->setTextColor(color);
  canvas->setCursor(x, y);
  canvas->print(text);
}

void drawModeSwitcherDirect() {
  int y = 166;

  drawTextWithShadowDirect("VIDEO", 39, y, currentMode == 0 ? C_IOS_BLUE : C_WHITE);
  drawTextWithShadowDirect("PHOTO", 166, y, currentMode == 1 ? C_IOS_BLUE : C_WHITE);

  if (currentMode == 0) {
    canvas->fillRoundRect(46, y + 13, 19, 3, 1, C_IOS_BLUE);
  } else {
    canvas->fillRoundRect(174, y + 13, 20, 3, 1, C_IOS_BLUE);
  }
}

void drawShutterDirect() {
  int cx = 120;
  int cy = 204;

  canvas->fillCircle(cx + 1, cy + 2, 31, C_BLACK);

  if (currentMode == 0) {
    canvas->fillCircle(cx, cy, 29, C_WHITE);
    canvas->fillCircle(cx, cy, 23, C_BLACK);

    if (isRecording) {
      canvas->fillRoundRect(cx - 10, cy - 10, 20, 20, 4, C_RED);
    } else {
      canvas->fillCircle(cx, cy, 15, C_RED);
    }
  } else {
    canvas->fillCircle(cx, cy, 30, C_WHITE);
    canvas->fillCircle(cx, cy, 24, C_BLACK);
    canvas->fillCircle(cx, cy, 18, C_WHITE);
  }
}

void drawRecordingDirect() {
  if (isRecording) {
    canvas->fillCircle(120, 38, 5, C_RED);
    canvas->setTextSize(1);
    canvas->setTextColor(C_RED);
    canvas->setCursor(132, 34);
    canvas->print("REC");
  }
}

void drawThickLine(int x0, int y0, int x1, int y1, uint16_t color) {
  canvas->drawLine(x0, y0, x1, y1, color);
  canvas->drawLine(x0 + 1, y0, x1 + 1, y1, color);
  canvas->drawLine(x0 - 1, y0, x1 - 1, y1, color);
  canvas->drawLine(x0, y0 + 1, x1, y1 + 1, color);
  canvas->drawLine(x0, y0 - 1, x1, y1 - 1, color);
}

void drawPhotoFeedback() {
  unsigned long now = millis();

  if (now < photoFlashUntilMs) {
    canvas->fillScreen(C_WHITE);
  }

  if (now < photoSavedUntilMs) {
    int cx = 120;
    int cy = 104;

    canvas->fillCircle(cx + 2, cy + 3, 32, C_BLACK);
    canvas->fillCircle(cx, cy, 30, C_WHITE);

    drawThickLine(cx - 13, cy, cx - 4, cy + 10, C_GREEN);
    drawThickLine(cx - 4, cy + 10, cx + 15, cy - 12, C_GREEN);

    canvas->setTextSize(1);
    canvas->setTextColor(C_WHITE);
    canvas->setCursor(103, 142);
    canvas->print("SAVED");
  }
}

void drawOverlay() {
  drawRecordingDirect();
  drawStickerIconDirect();
  drawModeSwitcherDirect();
  drawShutterDirect();
}

// ===============================
// Save RGB565 frame as JPG
// ===============================
bool writeBufferToSD(const String& path, const uint8_t *data, size_t length, const char *label) {
  if (!data || length == 0) {
    Serial.printf("%s save skipped: empty buffer\n", label);
    if (SD.exists(path)) {
      SD.remove(path);
    }
    return false;
  }

  if (SD.exists(path)) {
    SD.remove(path);
  }

  File file = SD.open(path, FILE_WRITE);
  if (!file) {
    Serial.printf("%s file open failed\n", label);
    return false;
  }

  size_t written = file.write(data, length);
  file.close();

  if (written != length) {
    Serial.printf("%s partial write: %u/%u bytes\n",
                  label, (unsigned)written, (unsigned)length);
    SD.remove(path);
    return false;
  }

  Serial.printf("%s saved: %u bytes\n", label, (unsigned)written);
  return true;
}

bool saveRGB565FrameAsJPGWithQuality(camera_fb_t *fb, String path, int quality) {
  if (!fb || fb->format != PIXFORMAT_RGB565) {
    Serial.println("Unsupported RGB565 frame for JPG save");
    return false;
  }

  uint8_t *jpgBuf = NULL;
  size_t jpgLen = 0;

  bool ok = fmt2jpg(
    fb->buf,
    fb->len,
    fb->width,
    fb->height,
    PIXFORMAT_RGB565,
    quality,
    &jpgBuf,
    &jpgLen
  );

  if (!ok || jpgBuf == NULL || jpgLen == 0) {
    Serial.println("JPG conversion failed");
    if (jpgBuf) free(jpgBuf);
    return false;
  }

  bool saved = writeBufferToSD(path, jpgBuf, jpgLen, "JPG");
  free(jpgBuf);

  if (saved) {
    Serial.printf("JPG details: quality=%d, frame=%dx%d\n", quality, fb->width, fb->height);
  }

  return saved;
}

bool saveRGB565FrameAsJPG(camera_fb_t *fb, String path) {
  return saveRGB565FrameAsJPGWithQuality(fb, path, 92);
}

bool saveNativeJPGFrame(camera_fb_t *fb, String path) {
  if (!fb || fb->format != PIXFORMAT_JPEG || fb->len == 0) {
    Serial.println("Unsupported native JPG frame");
    return false;
  }

  bool saved = writeBufferToSD(path, fb->buf, fb->len, "Native JPG");
  if (saved) {
    Serial.printf("Native JPG details: frame=%dx%d\n", fb->width, fb->height);
  }

  return saved;
}

bool configureCameraSensor(pixformat_t pixelFormat, framesize_t frameSize, int jpegQuality) {
  sensor_t *s = esp_camera_sensor_get();
  if (!s) {
    Serial.println("Camera sensor not available");
    return false;
  }

  bool ok = true;

  if (s->set_pixformat(s, pixelFormat) != 0) {
    Serial.println("set_pixformat failed");
    ok = false;
  }
  delay(80);

  if (s->set_framesize(s, frameSize) != 0) {
    Serial.println("set_framesize failed");
    ok = false;
  }
  delay(80);

  if (pixelFormat == PIXFORMAT_JPEG && s->set_quality(s, jpegQuality) != 0) {
    Serial.println("set_quality failed");
    ok = false;
  }
  delay(120);

  return ok;
}

void restorePreviewCameraMode() {
  Serial.println("Restoring fast RGB565 preview...");

  configureCameraSensor(PIXFORMAT_RGB565, PREVIEW_FRAME_SIZE, 12);
  applySensorTuning();
  flushCameraFrames(2, 50);
}

bool enterPhotoCaptureFrameSize(bool *didSwitch) {
  *didSwitch = false;

  if ((int)PHOTO_CAPTURE_FRAME_SIZE == (int)PREVIEW_FRAME_SIZE) {
    flushCameraFrames(1, 35);
    return true;
  }

  Serial.println("Switching to regular photo size...");

  if (!configureCameraSensor(PIXFORMAT_RGB565, PHOTO_CAPTURE_FRAME_SIZE, 12)) {
    Serial.println("Photo size switch failed; staying in preview size");
    restorePreviewCameraMode();
    return false;
  }

  applySensorTuning();
  flushCameraFrames(2, 40);
  *didSwitch = true;
  return true;
}

bool captureNativeJPGPhoto(String path, framesize_t frameSize, const char *label) {
  Serial.print("Trying native JPG photo ");
  Serial.println(label);

  if (!configureCameraSensor(PIXFORMAT_JPEG, frameSize, HQ_PHOTO_JPEG_QUALITY)) {
    return false;
  }

  flushCameraFrames(2, 90);

  camera_fb_t *fb = esp_camera_fb_get();
  if (!fb) {
    Serial.println("Native JPG capture failed");
    return false;
  }

  bool ok = saveNativeJPGFrame(fb, path);
  esp_camera_fb_return(fb);

  return ok;
}

// ===============================
// Safe regular photo capture
// ===============================
// This is intentionally NOT high-res reinit.
// The high-res reinit was causing board restart in gray-heart mode.
// This version saves the current stable RGB565 preview frame without camera reinit.
bool captureRegularFullFramePhoto(String path) {
  Serial.println("Safe regular photo capture...");

  bool didSwitch = false;
  bool photoSizeReady = enterPhotoCaptureFrameSize(&didSwitch);

  camera_fb_t *fb = esp_camera_fb_get();
  if (!fb) {
    Serial.println("Regular capture failed");
    if (didSwitch || !photoSizeReady) {
      restorePreviewCameraMode();
    }
    return false;
  }

  bool ok = saveRGB565FrameAsJPGWithQuality(fb, path, 95);
  esp_camera_fb_return(fb);

  if (didSwitch) {
    restorePreviewCameraMode();
  }

  return ok;
}

bool captureRegularHighQualityPhoto(String path) {
  statusText = "HQ photo";

  bool ok = captureNativeJPGPhoto(path, HQ_PHOTO_FRAME_SIZE, "primary");

  if (!ok) {
    Serial.println("Primary HQ failed; trying fallback");
    ok = captureNativeJPGPhoto(path, HQ_PHOTO_FALLBACK_FRAME_SIZE, "fallback");
  }

  restorePreviewCameraMode();

  if (ok) {
    return true;
  }

  Serial.println("Native JPG photo failed; falling back to safe QVGA");
  statusText = "Safe photo";
  return captureRegularFullFramePhoto(path);
}

bool captureRegularBestPhoto(String path) {
#if ENABLE_EXPERIMENTAL_HQ_PHOTO
  return captureRegularHighQualityPhoto(path);
#else
  statusText = "Safe photo";
  return captureRegularFullFramePhoto(path);
#endif
}
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
void loop() {
  unsigned long now = millis();

  server.handleClient();
  updateTouch();
  updateVideoRecording();
  if (isRecording || pendingTouchTap) {
    updateTouch();
  }

  if (showSplash && now - splashStartMs > SPLASH_DURATION_MS) {
    showSplash = false;
  }

  if (!showSplash && !isCapturing && now - lastPreviewMs >= PREVIEW_INTERVAL_MS) {
    lastPreviewMs = now;
    unsigned long frameStartMs = millis();

    if (isStickerModeEnabled()) {
      drawStickerPreviewToCanvas();
    } else {
      drawLivePreviewToCanvas();
    }

    updateTouch();

    drawOverlay();
    drawPhotoFeedback();

    unsigned long flushStartMs = millis();
    canvas->flush();
    unsigned long frameEndMs = millis();
    recordPreviewStats(frameStartMs, flushStartMs, frameEndMs);
  }

  delay(1);
}

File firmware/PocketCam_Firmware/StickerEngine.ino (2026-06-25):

// ===============================
// StickerEngine.ino
// PocketCam / Creator Cam — soft color modes for ESP32
//
// Heart cycles:
// gray clean -> Cream Film -> Mint Milk -> Blue Milk -> gray clean
//
// These modes intentionally avoid stickers, frames, and backgrounds. The photo
// stays clean; only the color recipe changes.
// ===============================

// From main file
bool saveRGB565FrameAsJPG(camera_fb_t *fb, String path);
bool writeBufferToSD(const String& path, const uint8_t *data, size_t length, const char *label);
void pollTouchDuringDraw();

// From PhotoFilters.ino
uint16_t ccApplyPhotoFilter(uint16_t normalRGB565, int x, int y, int mode);
uint16_t ccApplyPhotoFilterFastPreview(uint16_t normalRGB565, int mode);

static const int ST_MODE_CREAM = 0;
static const int ST_MODE_MINT = 1;
static const int ST_MODE_BLUE = 2;
static const int ST_COLOR_MODE_COUNT = 3;
static const int ST_REGULAR_MODE = 3;

static const unsigned long ST_HEART_TAP_LOCKOUT_MS = 280;
static int stBackgroundMode = ST_REGULAR_MODE;
static unsigned long stLastHeartTapMs = 0;

// ===============================
// Public API used by main file
// ===============================
bool isStickerModeEnabled() {
  return stBackgroundMode != ST_REGULAR_MODE;
}

bool tryHandleStickerTouch(uint8_t x, uint8_t y) {
  int cx = 34;
  int cy = 58;
  int r = 26;

  int dx = (int)x - cx;
  int dy = (int)y - cy;

  if ((dx * dx + dy * dy) <= (r * r)) {
    unsigned long now = millis();
    if (now - stLastHeartTapMs < ST_HEART_TAP_LOCKOUT_MS) {
      return true;
    }

    stLastHeartTapMs = now;

    if (stBackgroundMode == ST_REGULAR_MODE) {
      stBackgroundMode = ST_MODE_CREAM;
    } else if (stBackgroundMode >= 0 && stBackgroundMode < ST_COLOR_MODE_COUNT - 1) {
      stBackgroundMode++;
    } else {
      stBackgroundMode = ST_REGULAR_MODE;
    }

    Serial.print("Soft color mode = ");
    Serial.println(stBackgroundMode);
    return true;
  }

  return false;
}

// ===============================
// Helpers
// ===============================
static int stClampInt(int v, int lo, int hi) {
  if (v < lo) return lo;
  if (v > hi) return hi;
  return v;
}

static inline uint8_t stClamp8(int v) {
  if (v < 0) return 0;
  if (v > 255) return 255;
  return (uint8_t)v;
}

static uint16_t stRGB565(int r, int g, int b) {
  r = stClamp8(r);
  g = stClamp8(g);
  b = stClamp8(b);

  return ((r & 0xF8) << 8) |
         ((g & 0xFC) << 3) |
         (b >> 3);
}

static uint16_t stSwap565(uint16_t p) {
  return (p >> 8) | (p << 8);
}

static uint16_t stAccent() {
  if (stBackgroundMode == ST_MODE_CREAM) return stRGB565(245, 178, 86);
  if (stBackgroundMode == ST_MODE_MINT) return stRGB565(112, 190, 150);
  if (stBackgroundMode == ST_MODE_BLUE) return stRGB565(94, 160, 218);
  return C_SOFT_GRAY;
}

static int stPhotoFilterMode() {
  if (stBackgroundMode == ST_MODE_CREAM) return 5; // cream film
  if (stBackgroundMode == ST_MODE_MINT) return 2;  // mint milk
  if (stBackgroundMode == ST_MODE_BLUE) return 6;  // blue milk
  return 4;
}

static uint16_t stCameraPixelNormal(uint16_t *pixels, int frameWidth, int sx, int sy) {
  sx = stClampInt(sx, 0, 239);
  sy = stClampInt(sy, 0, 239);

  int cropX = frameWidth > 240 ? (frameWidth - 240) / 2 : 0;
  uint16_t raw = pixels[sy * frameWidth + cropX + sx];
  return stSwap565(raw);
}

static uint16_t stFilteredCameraPixel(uint16_t *pixels, int frameWidth, int sx, int sy, int outX, int outY) {
  uint16_t normal = stCameraPixelNormal(pixels, frameWidth, sx, sy);
  return ccApplyPhotoFilter(normal, outX, outY, stPhotoFilterMode());
}

static uint16_t stComposeLayoutPixel(uint16_t *pixels, int frameWidth, int x, int y) {
  if (stBackgroundMode == ST_MODE_CREAM ||
      stBackgroundMode == ST_MODE_MINT ||
      stBackgroundMode == ST_MODE_BLUE) {
    return stFilteredCameraPixel(pixels, frameWidth, x, y, x, y);
  }

  return stCameraPixelNormal(pixels, frameWidth, x, y);
}

// ===============================
// Decorative preview drawing
// ===============================
static void stDrawHeartIcon(int cx, int cy, uint16_t color) {
  canvas->fillCircle(cx - 5, cy - 4, 5, color);
  canvas->fillCircle(cx + 5, cy - 4, 5, color);
  canvas->fillTriangle(cx - 11, cy - 2, cx + 11, cy - 2, cx, cy + 13, color);
}

void drawStickerIconDirect() {
  int x = 34;
  int y = 58;

  canvas->fillCircle(x + 1, y + 1, 16, C_BLACK);
  canvas->fillCircle(x, y, 16, C_WHITE);

  uint16_t heartColor = C_SOFT_GRAY;
  if (stBackgroundMode != ST_REGULAR_MODE) {
    heartColor = stAccent();
  }

  stDrawHeartIcon(x, y, heartColor);
}

// ===============================
// Preview composition
// ===============================
void drawStickerPreviewToCanvas() {
  if (!cameraOK || isCapturing) return;

  camera_fb_t *fb = esp_camera_fb_get();
  if (!fb) {
    Serial.println("Sticker preview frame failed");
    return;
  }

  if (fb->format == PIXFORMAT_RGB565 && fb->width >= 240 && fb->height >= 240) {
    uint16_t *pixels = (uint16_t *)fb->buf;
    uint16_t *dst = canvas->getFramebuffer();
    int filterMode = stPhotoFilterMode();
    int cropX = fb->width > 240 ? (fb->width - 240) / 2 : 0;

    if (!dst) {
      Serial.println("Sticker preview framebuffer missing");
      esp_camera_fb_return(fb);
      return;
    }

    for (int y = 0; y < 240; y++) {
      uint16_t *srcLine = pixels + (y * fb->width) + cropX;
      uint16_t *dstLine = dst + (y * 240);

      for (int x = 0; x < 240; x++) {
        uint16_t normal = stSwap565(srcLine[x]);
        dstLine[x] = ccApplyPhotoFilterFastPreview(normal, filterMode);
      }

      if ((y & 0x0F) == 0) {
        pollTouchDuringDraw();
        yield();
      }
    }
  } else {
    Serial.printf("Bad sticker preview frame: %dx%d format=%d len=%u\n",
      fb->width, fb->height, fb->format, (unsigned)fb->len);
  }

  esp_camera_fb_return(fb);
}

static bool stEncodeRGB565JPG(
  uint8_t *rgbData,
  size_t rgbLen,
  int width,
  int height,
  int quality,
  uint8_t **jpgBuf,
  size_t *jpgLen
) {
  *jpgBuf = NULL;
  *jpgLen = 0;

  bool ok = fmt2jpg(
    rgbData,
    rgbLen,
    width,
    height,
    PIXFORMAT_RGB565,
    quality,
    jpgBuf,
    jpgLen
  );

  if (!ok || *jpgBuf == NULL || *jpgLen == 0) {
    if (*jpgBuf) {
      free(*jpgBuf);
      *jpgBuf = NULL;
    }
    *jpgLen = 0;
    return false;
  }

  return true;
}
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

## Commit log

2026-06-25 Initial PocketCam project structure
    [accent_panel.stl, back_cover.stl, bezel_rings.stl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]
2026-06-25 Simplify CAD license
